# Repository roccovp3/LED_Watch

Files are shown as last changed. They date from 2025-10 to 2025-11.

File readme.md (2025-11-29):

# LED Watch
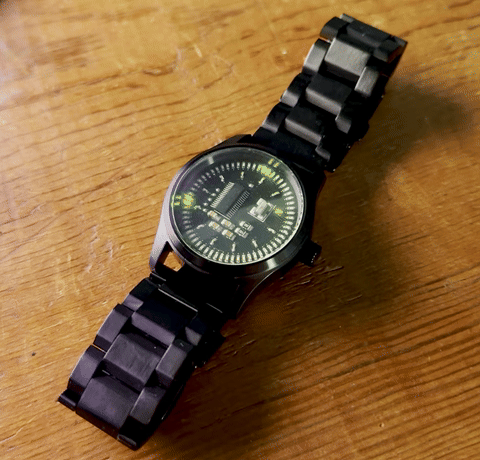
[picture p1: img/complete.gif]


This is a design for a digital LED watch that fits in a standard watch case. The watch shows the hours on the inner ring of 12 LEDs, and shows the minutes and seconds simultaneously on the outer ring of 60 LEDs. Time is adjustable through a switch in the crown that can be accessed with a paperclip.

## Electronics
A TI MSPM0 microcontroller controls a charlieplexed LED matrix of all 72 LEDs with 9 GPIO pins. Charlieplexing was chosen as it would otherwise take 17 GPIO pins to control the matrix with the more traditional wiring method. Timing is done via an external TCXO to minimize drift.

I chose the MSPM0 because I already had the development kit, and I was familiar with the device. With a project this simple, the MSPM0's low power consumption, minimal external component requirements, and integrated voltage regulator made it an adequate choice. In a future revision I could even opt for one of its smaller packages.

As for the LEDs, they are all 0402 packages with the inner ones being a yellow-green and the outer ones being a more solid green. In hindsight I would have opted for the green LEDs for everything because they have better diffusion and brightness and their package was much easier to solder. I knew when assembling that choosing the right current limiting resistors to set the maximum brightness was going to be trial and error, but I was surprised at just how much resistance I was able to put on the GPIO pins while keeping the LEDs more than bright enough for a well lit room. Each GPIO pin has 2kΩ on it, meaning the LEDs see 4kΩ each. With a 2.0V drop this means the maximum current through any given LED is about (3.3-2.0)/4000 = 300uA. Since the way the software is written means exactly one LED is on at all times, 300uA is the entire contribution of system current from the LEDs.

Powering this device required careful thought. I wanted to optimize for runtime given the space constraints, and it was hard to beat a coin-cell for this purpose. I chose the CR2032 both because it and it's holder fit nicely on the back of the PCB as well as their wide availability. The CR2450 was a tempting alternative, but I opted for the lower capacity (and smaller) CR2032 because of how easy they are to find. Initially, I thought a voltage regulator was necessary for this project which would have hurt battery life and required more components to be packed onto the PCB. Luckily, the MSPM0 has a wide input voltage range of 1.62 to 3.6V, making the CR2032 suitable to power the device throughout its entire lifespan (CR2032 batteries start at about 3.0V and die at about 1.8V).

## Physical Design
The 29.6mm PCB diameter was chosen to fit in a standard watch case. The watch case I used for this project claimed to fit a 28.5 to 29.2mm watch dial. Other research indicated that 29.5mm was the typical maximum dial size for the movement designed to fit in this case. The 29.6mm diameter allowed me to slowly sand away the edge of the PCB until the fit in the case was perfectly snug. The final diameter after sanding ended up being about 29.3mm. I was also careful to leave myself some space to sand by not routing traces near the board edge.

I chose a low-profile momentary switch on the back of the board to serve as an input for setting the time. This switch aligns well with the crown, making it accessible even when the watch is fully assembled. A challenge I would like to tackle in a future revision is attaching the crown to the switch so that it remains attached to the watch at all times and serves as a button itself. As of now, the crown completely unscrews from the watch making it easy to lose.

6 pads are exposed for the signals required to program the microcontroller. This programming method works, but in a future revision it would be nice to find a small connector so I don't have to solder wires to the board every time I think of a way to improve the firmware.

## Firmware
The firmware for the watch is minimal. The TCXO causes an interrupt every 32kHz. On every interrupt a master 15-bit (32768 possible values) counter is incremented. Every time the counter rolls over, the seconds LED updates as well as the minutes and hours if necessary. Between rollovers, the master counter serves as a way to define which of the three LEDs is on in the matrix. Charlieplexing relies on persistence of vision because only one LED can be on at one time. To do this, I look at the lower 7 bits (128 values) of the counter and whether those lower bits are in one of three ranges dictates which of the three possible LEDs is on (in fact, to compensate for my hour LEDs being dimmer, I give them more on-time by making their share of these 128 values larger than the minute/second LEDs). I choose 7 bits because choosing a larger number slows down the switching between the three LEDs enough to make flickering visible on my phone camera. On a 32kHz clock, to cycle through all 128 values takes about 3.9ms. A camera recording at 120 FPS captures a frame every 8.3ms. Becuase our period is less than the camera's, we avoid the flicker by guaranteeing all three LEDs are on at some point during each frame's exposure.

The only other part of the firmware is input management. The crown button allows the user to set the time. Pressing the button for less than a second will increment the hour, minute, or second. Pressing the button for more than a second will cycle between setting the hour, minute, or second.

When the microcontroller is not processing interrupts related to either keeping the time or setting the time, it is in standby mode to minimize power consumption.

## Images

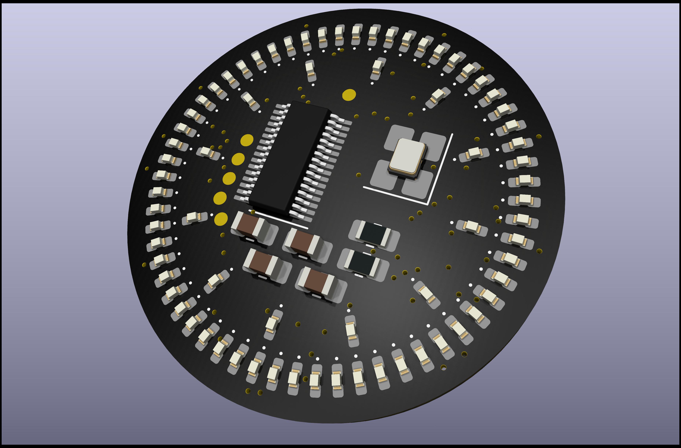
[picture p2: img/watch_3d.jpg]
watch_3d


KiCad 3D Model

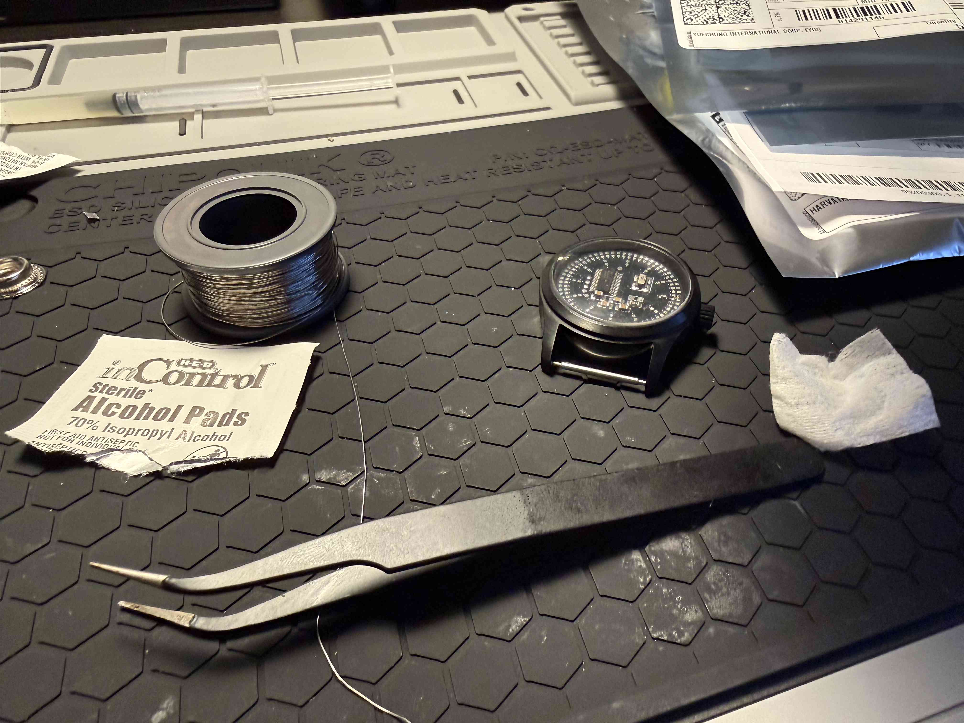
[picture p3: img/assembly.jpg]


Partially assembled. Getting the inner LEDs down was tricky as unlike the package for the outer ones, the pads are only exposed on the bottom and not on the sides.

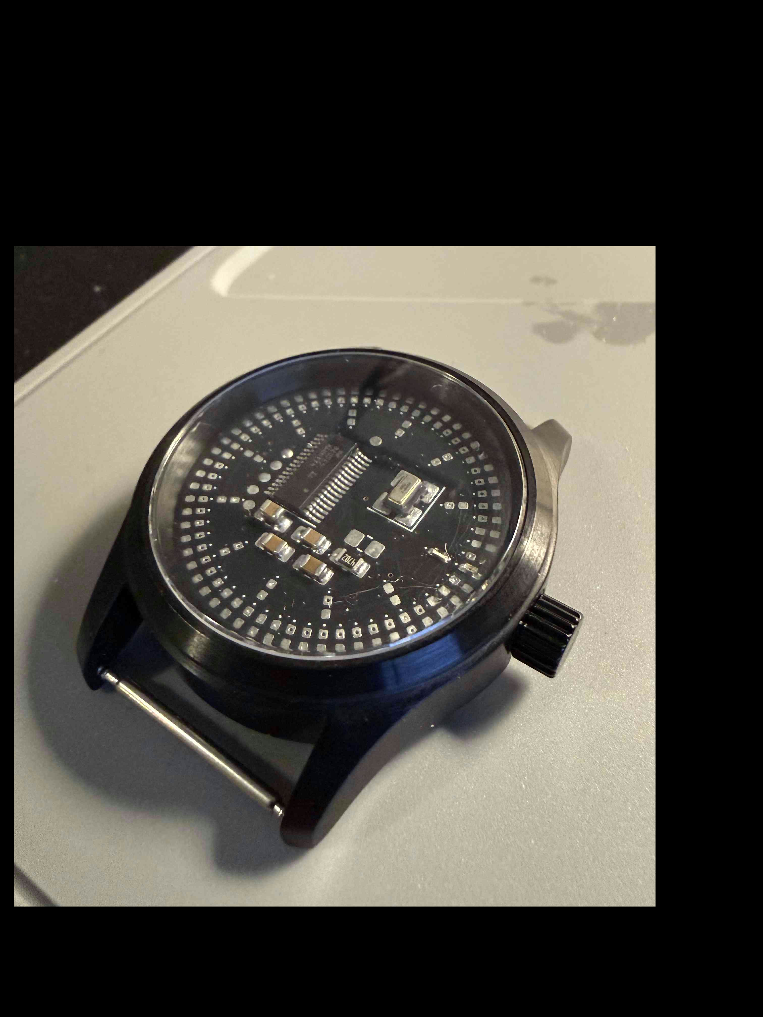
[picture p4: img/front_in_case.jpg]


Paritally assembled for a test fit in the case. I was surprise at how well it fit first try. The components had ample clearance between them and the glass. The PCB rests on a lip that provides this spacing.

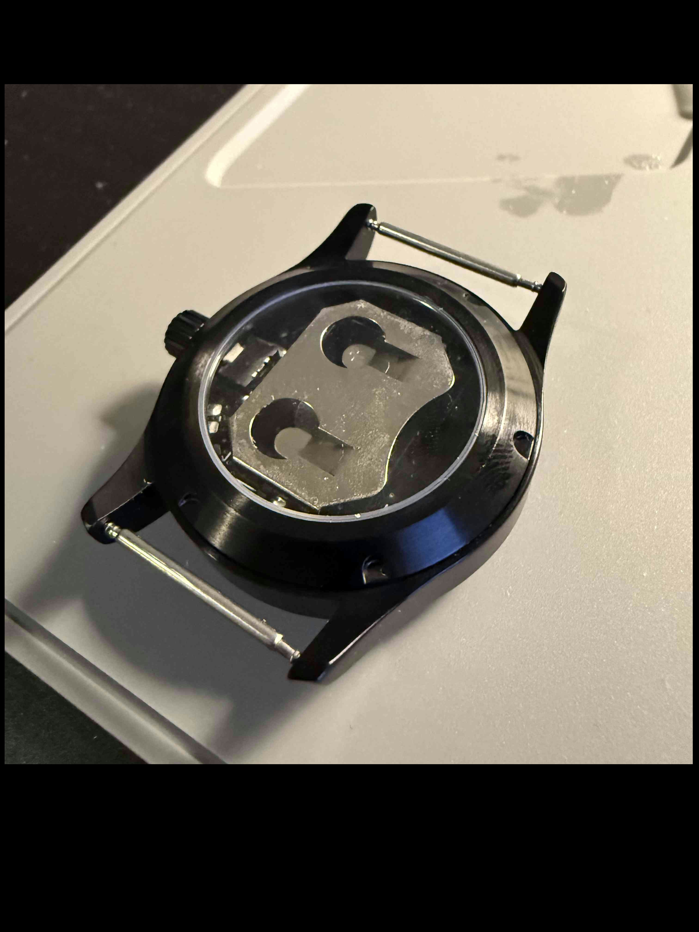
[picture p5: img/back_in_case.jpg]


Back of the case where the battery holder and switch can be seen. Getting a watch case with a clear back was definitely the correct decision :-)

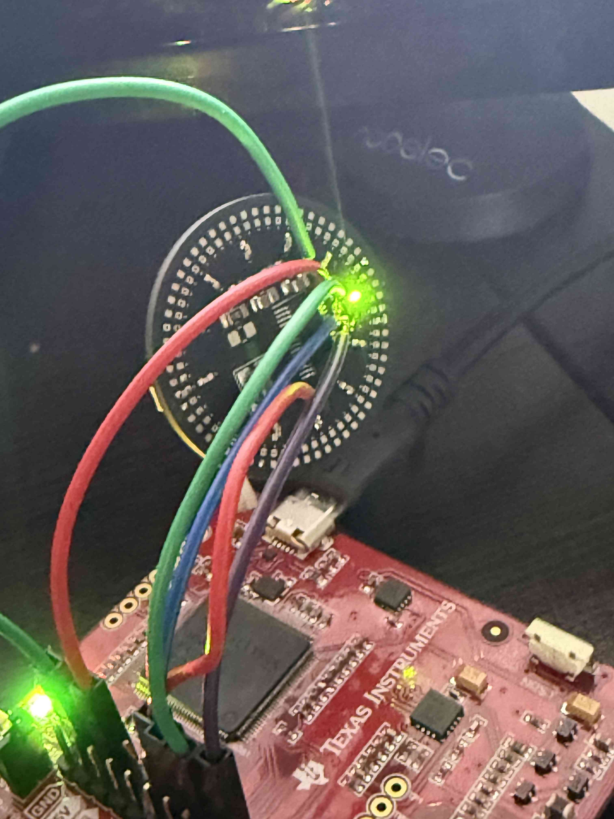
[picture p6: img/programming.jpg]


Programming with an MSPM0 development board. These wires are pretty annoying, but they work!

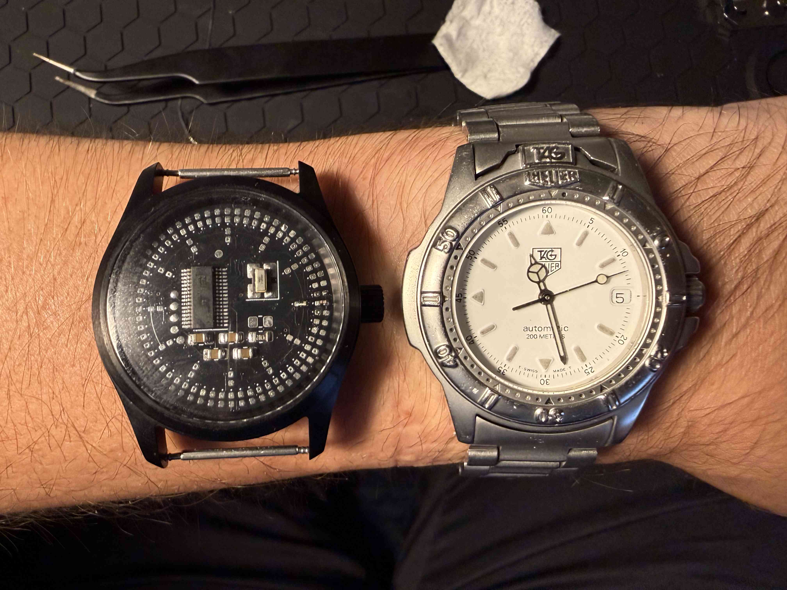
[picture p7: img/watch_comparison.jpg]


Size comparison with my watch.

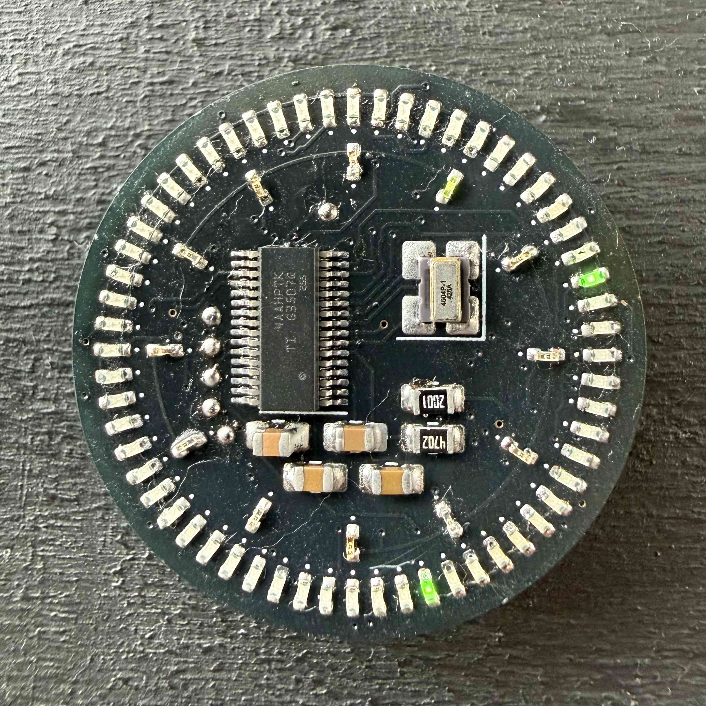
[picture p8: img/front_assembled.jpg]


Fully assembled. It's 1:12:27!

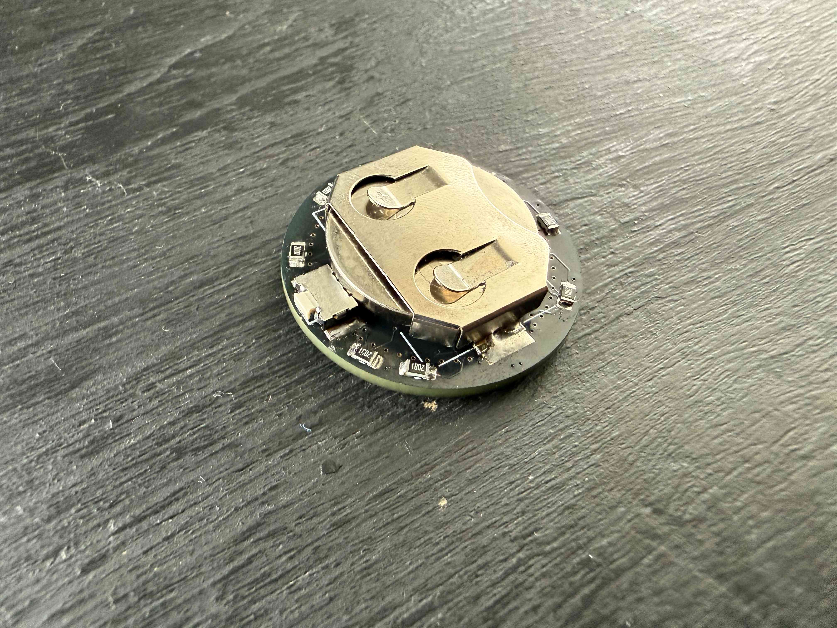
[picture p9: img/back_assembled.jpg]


Fully assembled (back). Battery installed.

## Videos
Videos with the watch fully working are in the img/ directory. GitHub does not currently support embedding videos over 10MB in readmes.

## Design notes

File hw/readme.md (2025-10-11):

This is a design for a digital LED watch that fits in a standard watch case.
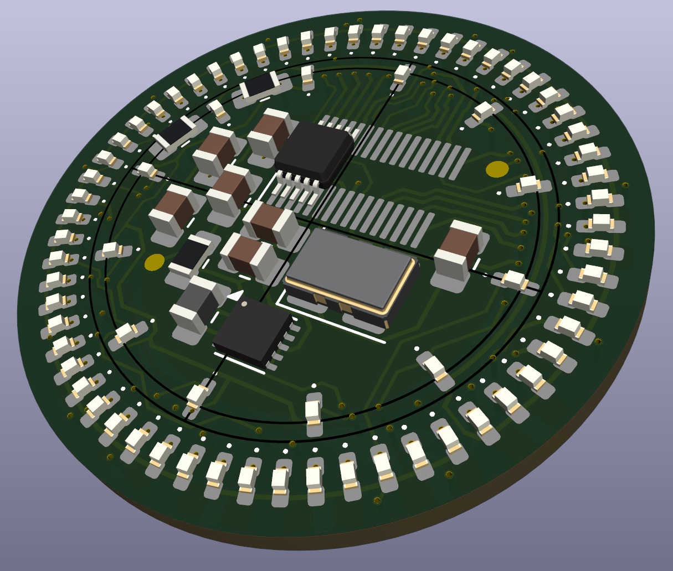
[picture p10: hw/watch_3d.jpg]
watch_3d


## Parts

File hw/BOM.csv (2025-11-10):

Reference | Qty | Value | Footprint | Datasheet | Unit Cost
BT1 | 1 | BAT-HLD-001 | led_watch:BAT_BAT-HLD-001 | https://4donline.ihs.com/images/VipMasterIC/IC/LNNC/LNNC-S-A0002913840/LNNC-S-A0002913840-1.pdf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 | $0.380
C4 | 1 | 10nF | 0805 | ~
C7 | 1 | 10uF | 0805 | ~
C8 | 1 | 0.1uF | 0805 | ~
C9 | 1 | 0.47uF | 0805 | ~
D1,D2,D3,D4,D5,D6,D7,D8,D9,D10,D11,D12,D13,D14,D15,D16,D17,D18,D19,D20,D21,D22,D23,D24,D25,D26,D27,D28,D29,D30,D31,D32,D33,D34,D35,D36,D37,D38,D39,D40,D41,D42,D43,D44,D45,D46,D47,D48,D49,D50,D51,D52,D53,D54,D55,D56,D57,D58,D59,D60,D61,D62,D63,D64,D65,D66,D67,D68,D69,D70,D71,D72 | 72 | LED_45deg | 0402 | ~ | $0.098
R1,R3,R5,R7,R9,R11,R13,R15,R17 | 9 | 2k | 0805 | ~
R19 | 1 | 47k | 0805 | ~
S1 | 1 | KSS223GLFG | KSS223GLFG | https://ckswitches.com/media/1463/kss.pdf | $0.970
U3 | 1 | M0G3507QDGS32RQ1 | led_watch:generic_VSSOP_0.5mm | https://www.ti.com/lit/ds/symlink/mspm0g3507-q1.pdf?ts=1726224116300 | $2.440
Y2 | 1 | TXC-7C | Oscillator:Oscillator_SMD_Abracon_ASE-4Pin_3.2x2.5mm_HandSoldering | http://www.txccorp.com/download/products/osc/7C_o.pdf | $3.190
 |  |  |  |  | $7.078 | Total

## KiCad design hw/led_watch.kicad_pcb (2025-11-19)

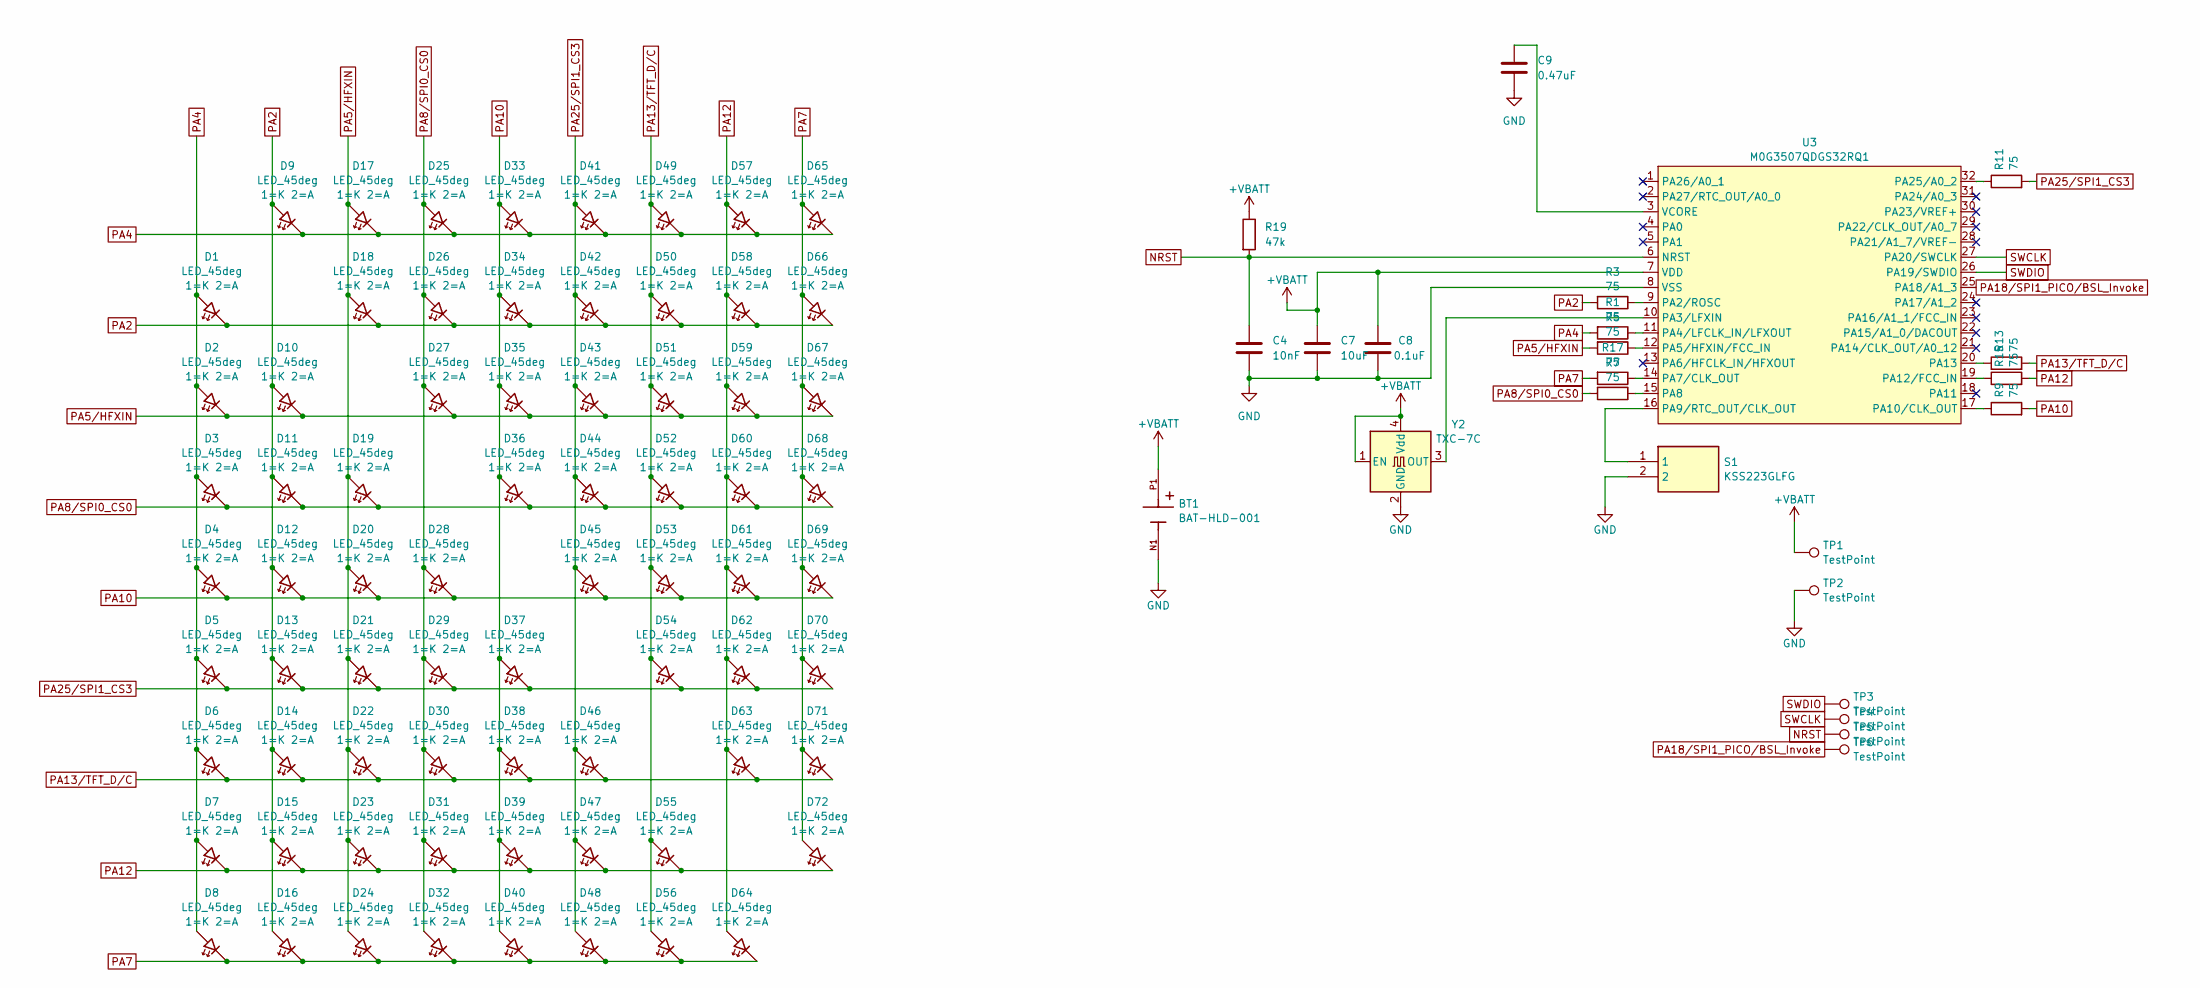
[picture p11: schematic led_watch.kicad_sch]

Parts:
BT1: BAT-HLD-001; BAT_BAT-HLD-001; PARTREV C
C4: 10nF; C_0805_2012Metric_Pad1.18x1.45mm_HandSolder
C7: 10uF; C_0805_2012Metric_Pad1.18x1.45mm_HandSolder
C8: 0.1uF; C_0805_2012Metric_Pad1.18x1.45mm_HandSolder
C9: 0.47uF; C_0805_2012Metric_Pad1.18x1.45mm_HandSolder
D1, D2, D3, D4, D5, D6, D7, D8, D9, D10, D11, D12, D13, D14, D15, D16, D17, D18, D19, D20, D21, D22, D23, D24, D25, D26, D27, D28, D29, D30, D31, D32, D33, D34, D35, D36, D37, D38, D39, D40, D41, D42, D43, D44, D45, D46, D47, D48, D49, D50, D51, D52, D53, D54, D55, D56, D57, D58, D59, D60, D61, D62, D63, D64, D65, D66, D67, D68, D69, D70, D71, D72: LED_45deg; LED_0402_1005Metric_Pad0.77x0.64mm_HandSolder
R1, R3, R5, R7, R9, R11, R13, R15, R17: 75; R_0805_2012Metric_Pad1.20x1.40mm_HandSolder
R19: 47k; R_0805_2012Metric_Pad1.20x1.40mm_HandSolder
S1: KSS223GLFG; Mouser Part Number 611-KSS223GLFG
TP1, TP2, TP3, TP4, TP5, TP6: TestPoint; TestPoint_Pad_D1.0mm
U3: M0G3507QDGS32RQ1; generic_VSSOP_0.5mm
Y2: TXC-7C; Oscillator_SMD_Abracon_ASE-4Pin_3.2x2.5mm_HandSoldering

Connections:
+VBATT: BT1.P1, BT1.P2, C7.1, C8.1, R19.1, TP1.1, U3.7 (VDD), Y2.1 (EN), Y2.4 (Vdd)
GND: BT1.N1, C4.2, C7.2, C8.2, C9.2, S1.2, TP2.1, U3.8 (VSS), Y2.2 (GND)
NRST: C4.1, R19.2, TP5.1, U3.6 (NRST)
unnamed: R3.1, U3.9 (PA2/ROSC)
unnamed: U3.10 (PA3/LFXIN), Y2.3 (OUT)
unnamed: R1.1, U3.11 (PA4/LFCLK_IN/LFXOUT)
unnamed: R5.1, U3.12 (PA5/HFXIN/FCC_IN)
unnamed: R17.1, U3.14 (PA7/CLK_OUT)
unnamed: R7.1, U3.15 (PA8)
unnamed: S1.1, U3.16 (PA9/RTC_OUT/CLK_OUT)
unnamed: R9.1, U3.17 (PA10/CLK_OUT)
unnamed: R15.1, U3.19 (PA12/FCC_IN)
unnamed: R13.1, U3.20 (PA13)
unnamed: R11.1, U3.32 (PA25/A0_2)
unnamed: C9.1, U3.3 (VCORE)
PA2: D1.1 (K), D9.2 (A), D10.2 (A), D11.2 (A), D12.2 (A), D13.2 (A), D14.2 (A), D15.2 (A), D16.2 (A), D18.1 (K), D26.1 (K), D34.1 (K), D42.1 (K), D50.1 (K), D58.1 (K), D66.1 (K), R3.2
PA4: D1.2 (A), D2.2 (A), D3.2 (A), D4.2 (A), D5.2 (A), D6.2 (A), D7.2 (A), D8.2 (A), D9.1 (K), D17.1 (K), D25.1 (K), D33.1 (K), D41.1 (K), D49.1 (K), D57.1 (K), D65.1 (K), R1.2
PA5/HFXIN: D2.1 (K), D10.1 (K), D17.2 (A), D18.2 (A), D19.2 (A), D20.2 (A), D21.2 (A), D22.2 (A), D23.2 (A), D24.2 (A), D27.1 (K), D35.1 (K), D43.1 (K), D51.1 (K), D59.1 (K), D67.1 (K), R5.2
PA7: D8.1 (K), D16.1 (K), D24.1 (K), D32.1 (K), D40.1 (K), D48.1 (K), D56.1 (K), D64.1 (K), D65.2 (A), D66.2 (A), D67.2 (A), D68.2 (A), D69.2 (A), D70.2 (A), D71.2 (A), D72.2 (A), R17.2
PA8/SPI0_CS0: D3.1 (K), D11.1 (K), D19.1 (K), D25.2 (A), D26.2 (A), D27.2 (A), D28.2 (A), D29.2 (A), D30.2 (A), D31.2 (A), D32.2 (A), D36.1 (K), D44.1 (K), D52.1 (K), D60.1 (K), D68.1 (K), R7.2
PA10: D4.1 (K), D12.1 (K), D20.1 (K), D28.1 (K), D33.2 (A), D34.2 (A), D35.2 (A), D36.2 (A), D37.2 (A), D38.2 (A), D39.2 (A), D40.2 (A), D45.1 (K), D53.1 (K), D61.1 (K), D69.1 (K), R9.2
PA12: D7.1 (K), D15.1 (K), D23.1 (K), D31.1 (K), D39.1 (K), D47.1 (K), D55.1 (K), D57.2 (A), D58.2 (A), D59.2 (A), D60.2 (A), D61.2 (A), D62.2 (A), D63.2 (A), D64.2 (A), D72.1 (K), R15.2
PA13/TFT_D/C: D6.1 (K), D14.1 (K), D22.1 (K), D30.1 (K), D38.1 (K), D46.1 (K), D49.2 (A), D50.2 (A), D51.2 (A), D52.2 (A), D53.2 (A), D54.2 (A), D55.2 (A), D56.2 (A), D63.1 (K), D71.1 (K), R13.2
PA18/SPI1_PICO/BSL_Invoke: TP6.1, U3.25 (PA18/A1_3)
PA25/SPI1_CS3: D5.1 (K), D13.1 (K), D21.1 (K), D29.1 (K), D37.1 (K), D41.2 (A), D42.2 (A), D43.2 (A), D44.2 (A), D45.2 (A), D46.2 (A), D47.2 (A), D48.2 (A), D54.1 (K), D62.1 (K), D70.1 (K), R11.2
SWCLK: TP4.1, U3.27 (PA20/SWCLK)
SWDIO: TP3.1, U3.26 (PA19/SWDIO)

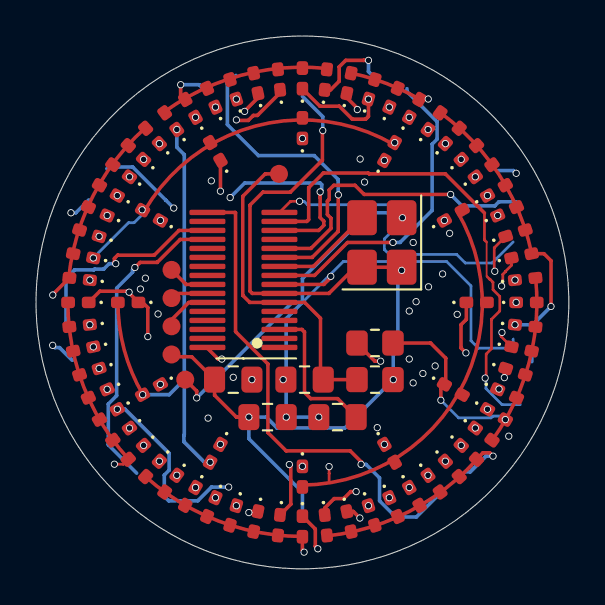
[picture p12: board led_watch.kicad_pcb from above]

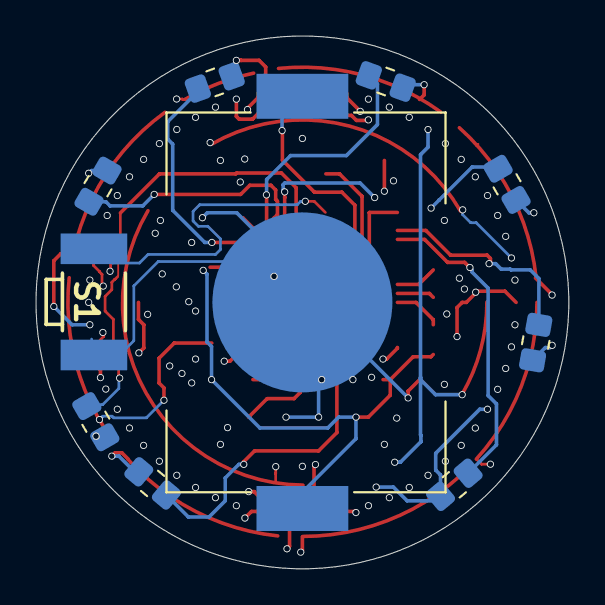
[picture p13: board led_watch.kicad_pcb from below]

Board: 4 copper layers, 29.6 x 29.6 mm, 96 parts (10 on the bottom side), 27 nets.

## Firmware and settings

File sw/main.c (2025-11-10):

/*
 * Copyright (c) 2021, Texas Instruments Incorporated
 * All rights reserved.
 *
 * Redistribution and use in source and binary forms, with or without
 * modification, are permitted provided that the following conditions
 * are met:
 *
 * *  Redistributions of source code must retain the above copyright
 *    notice, this list of conditions and the following disclaimer.
 *
 * *  Redistributions in binary form must reproduce the above copyright
 *    notice, this list of conditions and the following disclaimer in the
 *    documentation and/or other materials provided with the distribution.
 *
 * *  Neither the name of Texas Instruments Incorporated nor the names of
 *    its contributors may be used to endorse or promote products derived
 *    from this software without specific prior written permission.
 *
 * THIS SOFTWARE IS PROVIDED BY THE COPYRIGHT HOLDERS AND CONTRIBUTORS "AS IS"
 * AND ANY EXPRESS OR IMPLIED WARRANTIES, INCLUDING, BUT NOT LIMITED TO,
 * THE IMPLIED WARRANTIES OF MERCHANTABILITY AND FITNESS FOR A PARTICULAR
 * PURPOSE ARE DISCLAIMED. IN NO EVENT SHALL THE COPYRIGHT OWNER OR
 * CONTRIBUTORS BE LIABLE FOR ANY DIRECT, INDIRECT, INCIDENTAL, SPECIAL,
 * EXEMPLARY, OR CONSEQUENTIAL DAMAGES (INCLUDING, BUT NOT LIMITED TO,
 * PROCUREMENT OF SUBSTITUTE GOODS OR SERVICES; LOSS OF USE, DATA, OR PROFITS;
 * OR BUSINESS INTERRUPTION) HOWEVER CAUSED AND ON ANY THEORY OF LIABILITY,
 * WHETHER IN CONTRACT, STRICT LIABILITY, OR TORT (INCLUDING NEGLIGENCE OR
 * OTHERWISE) ARISING IN ANY WAY OUT OF THE USE OF THIS SOFTWARE,
 * EVEN IF ADVISED OF THE POSSIBILITY OF SUCH DAMAGE.
 */

#include "ti_msp_dl_config.h"
#include "LEDs.h"

uint32_t second_count = 0;
uint64_t master_count = 0;

uint8_t time_set_mode = 0;
void handle_button_press(void)
{
    next_led_out(time_set_mode);
}

void handle_button_long_press(void)
{
    time_set_mode = (time_set_mode + 1) % 3;
}

uint64_t timer_on_press = 0;
void GROUP1_IRQHandler(void)
{
    // Determine which pin triggered the interrupt
    switch (DL_GPIO_getPendingInterrupt(GPIOA)) {
        case DL_GPIO_IIDX_DIO3:  // Check if the interrupt was from PA3
            if (second_count == 0) {
                next_led_out(0);
            }
            led_out(second_count);
            second_count = (second_count + 1) % 32768;
            master_count++;
            break;

        case DL_GPIO_IIDX_DIO9:
            if(GPIOA->DIN31_0 & 0x200) {
                uint64_t delta = master_count - timer_on_press;
                if(delta < 32768) {
                    handle_button_press();
                } else {
                    handle_button_long_press();
                }
            }
            else {
                timer_on_press = master_count;
            }
            break;

        default:
            break;
    }
}

int main(void)
{
    SYSCFG_DL_init();
    
    NVIC_EnableIRQ(GPIOA_INT_IRQn);
    NVIC_EnableIRQ(TIMA0_INT_IRQn);

    while (1) {
        __WFI();
    }

    return 0;
}

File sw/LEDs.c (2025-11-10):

#include "ti_msp_dl_config.h"
#include "LEDs.h"

const watch_led_t min_60 = {0, 15, GPIO_GRP_0_PIN_4_PIN, GPIO_GRP_0_PIN_5_PIN, 34, 55};
const watch_led_t min_1 = {0, 16, GPIO_GRP_0_PIN_4_PIN, GPIO_GRP_0_PIN_2_PIN, 34, 21};
const watch_led_t min_2 = {0, 17, GPIO_GRP_0_PIN_12_PIN, GPIO_GRP_0_PIN_8_PIN, 14, 34};
const watch_led_t min_3 = {0, 18, GPIO_GRP_0_PIN_12_PIN, GPIO_GRP_0_PIN_5_PIN, 14, 35};
const watch_led_t min_4 = {0, 19, GPIO_GRP_0_PIN_12_PIN, GPIO_GRP_0_PIN_2_PIN, 14, 55};
const watch_led_t min_5 = {0, 20, GPIO_GRP_0_PIN_12_PIN, GPIO_GRP_0_PIN_4_PIN, 14, 21};
const watch_led_t min_6 = {0, 21, GPIO_GRP_0_PIN_13_PIN, GPIO_GRP_0_PIN_7_PIN, 14, 19};
const watch_led_t min_7 = {0, 22, GPIO_GRP_0_PIN_13_PIN, GPIO_GRP_0_PIN_12_PIN, 14, 10};
const watch_led_t min_8 = {0, 23, GPIO_GRP_0_PIN_13_PIN, GPIO_GRP_0_PIN_25_PIN, 14, 7};
const watch_led_t min_9 = {0, 24, GPIO_GRP_0_PIN_13_PIN, GPIO_GRP_0_PIN_10_PIN, 14, 9};
const watch_led_t min_10 = {0, 25, GPIO_GRP_0_PIN_13_PIN, GPIO_GRP_0_PIN_8_PIN, 34, 14};
const watch_led_t min_11 = {0, 26, GPIO_GRP_0_PIN_13_PIN, GPIO_GRP_0_PIN_5_PIN, 34, 35};
const watch_led_t min_12 = {0, 27, GPIO_GRP_0_PIN_13_PIN, GPIO_GRP_0_PIN_2_PIN, 34, 55};
const watch_led_t min_13 = {0, 28, GPIO_GRP_0_PIN_13_PIN, GPIO_GRP_0_PIN_4_PIN, 34, 21};
const watch_led_t min_14 = {0, 29, GPIO_GRP_0_PIN_25_PIN, GPIO_GRP_0_PIN_7_PIN, 14, 34};
const watch_led_t min_15 = {0, 30, GPIO_GRP_0_PIN_25_PIN, GPIO_GRP_0_PIN_12_PIN, 14, 35};
const watch_led_t min_16 = {0, 31, GPIO_GRP_0_PIN_25_PIN, GPIO_GRP_0_PIN_13_PIN, 14, 55};
const watch_led_t min_17 = {0, 32, GPIO_GRP_0_PIN_25_PIN, GPIO_GRP_0_PIN_10_PIN, 14, 21};
const watch_led_t min_18 = {0, 33, GPIO_GRP_0_PIN_25_PIN, GPIO_GRP_0_PIN_8_PIN, 14, 19};
const watch_led_t min_19 = {0, 34, GPIO_GRP_0_PIN_25_PIN, GPIO_GRP_0_PIN_5_PIN, 14, 10};
const watch_led_t min_20 = {0, 35, GPIO_GRP_0_PIN_25_PIN, GPIO_GRP_0_PIN_2_PIN, 14, 7};
const watch_led_t min_21 = {0, 36, GPIO_GRP_0_PIN_25_PIN, GPIO_GRP_0_PIN_4_PIN, 14, 9};
const watch_led_t min_22 = {0, 37, GPIO_GRP_0_PIN_10_PIN, GPIO_GRP_0_PIN_7_PIN, 34, 14};
const watch_led_t min_23 = {0, 38, GPIO_GRP_0_PIN_10_PIN, GPIO_GRP_0_PIN_12_PIN, 34, 35};
const watch_led_t min_24 = {0, 39, GPIO_GRP_0_PIN_10_PIN, GPIO_GRP_0_PIN_13_PIN, 34, 55};
const watch_led_t min_25 = {0, 40, GPIO_GRP_0_PIN_10_PIN, GPIO_GRP_0_PIN_25_PIN, 34, 21};
const watch_led_t min_26 = {0, 41, GPIO_GRP_0_PIN_10_PIN, GPIO_GRP_0_PIN_8_PIN, 14, 34};
const watch_led_t min_27 = {0, 42, GPIO_GRP_0_PIN_10_PIN, GPIO_GRP_0_PIN_5_PIN, 14, 35};
const watch_led_t min_28 = {0, 43, GPIO_GRP_0_PIN_10_PIN, GPIO_GRP_0_PIN_2_PIN, 14, 55};
const watch_led_t min_29 = {0, 44, GPIO_GRP_0_PIN_10_PIN, GPIO_GRP_0_PIN_4_PIN, 14, 21};
const watch_led_t min_30 = {0, 45, GPIO_GRP_0_PIN_8_PIN, GPIO_GRP_0_PIN_7_PIN, 14, 19};
const watch_led_t min_31 = {0, 46, GPIO_GRP_0_PIN_8_PIN, GPIO_GRP_0_PIN_12_PIN, 14, 10};
const watch_led_t min_32 = {0, 47, GPIO_GRP_0_PIN_8_PIN, GPIO_GRP_0_PIN_13_PIN, 14, 7};
const watch_led_t min_33 = {0, 48, GPIO_GRP_0_PIN_8_PIN, GPIO_GRP_0_PIN_25_PIN, 14, 9};
const watch_led_t min_34 = {0, 49, GPIO_GRP_0_PIN_8_PIN, GPIO_GRP_0_PIN_10_PIN, 34, 14};
const watch_led_t min_35 = {0, 50, GPIO_GRP_0_PIN_8_PIN, GPIO_GRP_0_PIN_5_PIN, 34, 35};
const watch_led_t min_36 = {0, 51, GPIO_GRP_0_PIN_8_PIN, GPIO_GRP_0_PIN_2_PIN, 34, 55};
const watch_led_t min_37 = {0, 52, GPIO_GRP_0_PIN_8_PIN, GPIO_GRP_0_PIN_4_PIN, 34, 21};
const watch_led_t min_38 = {0, 53, GPIO_GRP_0_PIN_5_PIN, GPIO_GRP_0_PIN_7_PIN, 14, 34};
const watch_led_t min_39 = {0, 54, GPIO_GRP_0_PIN_5_PIN, GPIO_GRP_0_PIN_12_PIN, 14, 35};
const watch_led_t min_40 = {0, 55, GPIO_GRP_0_PIN_5_PIN, GPIO_GRP_0_PIN_13_PIN, 14, 55};
const watch_led_t min_41 = {0, 56, GPIO_GRP_0_PIN_5_PIN, GPIO_GRP_0_PIN_25_PIN, 14, 21};
const watch_led_t min_42 = {0, 57, GPIO_GRP_0_PIN_5_PIN, GPIO_GRP_0_PIN_10_PIN, 14, 19};
const watch_led_t min_43 = {0, 58, GPIO_GRP_0_PIN_5_PIN, GPIO_GRP_0_PIN_8_PIN, 14, 10};
const watch_led_t min_44 = {0, 59, GPIO_GRP_0_PIN_5_PIN, GPIO_GRP_0_PIN_2_PIN, 14, 7};
const watch_led_t min_45 = {0, 60, GPIO_GRP_0_PIN_5_PIN, GPIO_GRP_0_PIN_4_PIN, 14, 9};
const watch_led_t min_46 = {0, 1, GPIO_GRP_0_PIN_2_PIN, GPIO_GRP_0_PIN_7_PIN, 34, 14};
const watch_led_t min_47 = {0, 2, GPIO_GRP_0_PIN_2_PIN, GPIO_GRP_0_PIN_12_PIN, 34, 35};
const watch_led_t min_48 = {0, 3, GPIO_GRP_0_PIN_2_PIN, GPIO_GRP_0_PIN_13_PIN, 34, 55};
const watch_led_t min_49 = {0, 4, GPIO_GRP_0_PIN_2_PIN, GPIO_GRP_0_PIN_25_PIN, 34, 21};
const watch_led_t min_50 = {0, 5, GPIO_GRP_0_PIN_2_PIN, GPIO_GRP_0_PIN_10_PIN, 14, 34};
const watch_led_t min_51 = {0, 6, GPIO_GRP_0_PIN_2_PIN, GPIO_GRP_0_PIN_8_PIN, 14, 35};
const watch_led_t min_52 = {0, 7, GPIO_GRP_0_PIN_2_PIN, GPIO_GRP_0_PIN_5_PIN, 14, 55};
const watch_led_t min_53 = {0, 8, GPIO_GRP_0_PIN_2_PIN, GPIO_GRP_0_PIN_4_PIN, 14, 21};
const watch_led_t min_54 = {0, 9, GPIO_GRP_0_PIN_4_PIN, GPIO_GRP_0_PIN_7_PIN, 14, 19};
const watch_led_t min_55 = {0, 10, GPIO_GRP_0_PIN_4_PIN, GPIO_GRP_0_PIN_12_PIN, 14, 10};
const watch_led_t min_56 = {0, 11, GPIO_GRP_0_PIN_4_PIN, GPIO_GRP_0_PIN_13_PIN, 14, 7};
const watch_led_t min_57 = {0, 12, GPIO_GRP_0_PIN_4_PIN, GPIO_GRP_0_PIN_25_PIN, 14, 9};
const watch_led_t min_58 = {0, 13, GPIO_GRP_0_PIN_4_PIN, GPIO_GRP_0_PIN_10_PIN, 34, 14};
const watch_led_t min_59 = {0, 14, GPIO_GRP_0_PIN_4_PIN, GPIO_GRP_0_PIN_8_PIN, 34, 35};


const watch_led_t hour_12 = {1, 3, GPIO_GRP_0_PIN_12_PIN, GPIO_GRP_0_PIN_25_PIN, 34, 55};
const watch_led_t hour_1 = {1, 4, GPIO_GRP_0_PIN_12_PIN, GPIO_GRP_0_PIN_10_PIN, 34, 21};
const watch_led_t hour_2 = {1, 5, GPIO_GRP_0_PIN_7_PIN, GPIO_GRP_0_PIN_12_PIN, 14, 34};
const watch_led_t hour_3 = {1, 6, GPIO_GRP_0_PIN_7_PIN, GPIO_GRP_0_PIN_13_PIN, 14, 35};
const watch_led_t hour_4 = {1, 7, GPIO_GRP_0_PIN_7_PIN, GPIO_GRP_0_PIN_25_PIN, 14, 55};
const watch_led_t hour_5 = {1, 8, GPIO_GRP_0_PIN_7_PIN, GPIO_GRP_0_PIN_10_PIN, 14, 21};
const watch_led_t hour_6 = {1, 9, GPIO_GRP_0_PIN_7_PIN, GPIO_GRP_0_PIN_8_PIN, 14, 19};
const watch_led_t hour_7 = {1, 10, GPIO_GRP_0_PIN_7_PIN, GPIO_GRP_0_PIN_5_PIN, 14, 10};
const watch_led_t hour_8 = {1, 11, GPIO_GRP_0_PIN_7_PIN, GPIO_GRP_0_PIN_2_PIN, 14, 7};
const watch_led_t hour_9 = {1, 12, GPIO_GRP_0_PIN_7_PIN, GPIO_GRP_0_PIN_4_PIN, 14, 9};
const watch_led_t hour_10 = {1, 1, GPIO_GRP_0_PIN_12_PIN, GPIO_GRP_0_PIN_7_PIN, 34, 14};
const watch_led_t hour_11 = {1, 2, GPIO_GRP_0_PIN_12_PIN, GPIO_GRP_0_PIN_13_PIN, 34, 35};
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

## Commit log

2025-10-16 4 layers, removed regulator
    [led_watch.kicad_pcb, led_watch.kicad_sch]
2025-10-17 remove half of resistors, routing cleanup
    [led_watch.kicad_pcb, led_watch.kicad_sch]
2025-10-18 rounded tracks
    [led_watch-rounded.kicad_pcb]
2025-10-23 add button
    [led_watch.kicad_pcb, led_watch.kicad_sch]
2025-11-08 functional sw with TCXO and hour LEDs moving at 1Hz
    [led_watch-rounded.kicad_pcb, led_watch.kicad_pcb, led_watch.kicad_sch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]
2025-11-08 clean up root repo dir
    [led_watch-rounded.kicad_pcb, led_watch.kicad_pcb, led_watch.kicad_sch]
2025-11-10 fix off by 15 error, add ability to adjust seconds
    [LEDs.c, main.c]
2025-11-10 cleanup hw dir, move readme
    [led_watch-rounded.kicad_pcb, led_watch.kicad_pcb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]
2025-11-10 add BOM
    [BOM.csv]
2025-11-19 add MSP 3D model
    [led_watch.kicad_pcb]
2025-11-30 change power policy to put watch in standby
